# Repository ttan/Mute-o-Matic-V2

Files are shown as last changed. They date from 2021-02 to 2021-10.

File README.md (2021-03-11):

# Mute-o-Matic V2

Hardware mute button and end call for MS Teams, with led indicator. Since I'm using both macOs and Windows, it has a nice and comfortable slide SPST switch on the side to select OS.

This was my test project for the new Raspberry Pi Pico; with ~4€ you get a crazy good microprocessor and implementing HID functionality is extremelty trivial.

The project is written in CircuitPython, using the [Adafruit HID Library](https://circuitpython.readthedocs.io/projects/hid/en/latest/index.html). Remember to copy the library file on the Pico together with the code.py file. ~~I used a transparent plastic container because... well, that's the only thing I had in the house and there's lockdown due to COVID-19. Feel free to buy me a 3D Printer ❤️~~ I actually ended up buying a 3D printer so here you are the Mute-o-Matic v2 in its fancy plastic box!

You can find the design of the case in the *case* folder. It's my first design, so expect some filing here and there, it needs some millimetric adjustments.

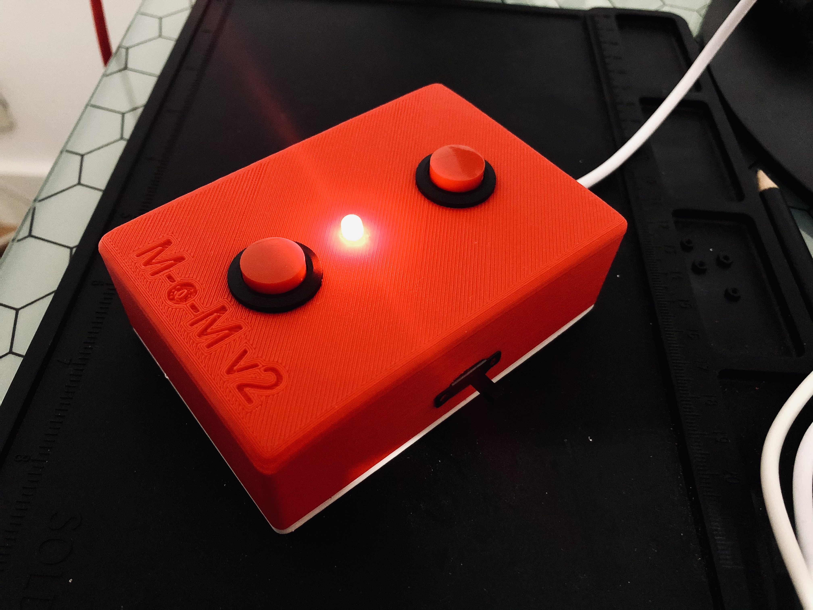
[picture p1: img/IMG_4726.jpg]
Mute-o-matic from the top


## A random Fritzing here

This is just to give you a idea of what's doing what.

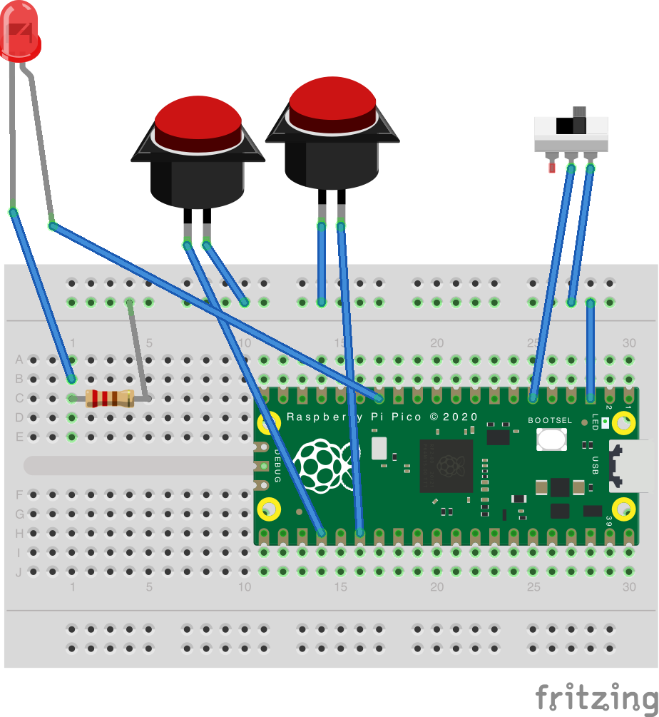
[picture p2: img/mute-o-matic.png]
Fritzing


## How it works
🚀 Rocket science! Jokes aside, it's just a HID which sends shortcuts defined in MS Teams, according to the OS selected with the side switch.
For Windows:
- *CTRL + Shift + M* to toggle the mute (and the led)
- *CTRL + Shift + B* to close the call (for strange reasons, this is not a documented shortcut on Teams official page)

For macOs (For macOs, cmd is mapped to GUI. I guess in Windows this would be the Windows logo):
- *CMD + Shift + M* to toggle the mute (and the led)
- *CMD + Shift + B* to close the call (guess what, this is also not a documented shortcut on Teams official page)

Easy. I just needed something to quickly mute/unmute the calls because I tend to get distracted and racing to find the proper button with the mouse is too hard.

## Parts used
- [Raspberry Pi Pico](https://www.raspberrypi.org/documentation/pico/getting-started/)
- 2 x Panel mount push button (Normally open)
- 1 x Red Led
- 1 x SPST slide switch
- 1 X 220 ohm resistance

## Windows only improvement
On my personal version of the Mute-o-Matic V2, I included another command which brings Teams on focus before toggling mute. This can be done with an idiot trick: pin Teams' icon in the bar (how is it called? the one below) and count what number is it starting from the left. You can switch to that with the shortcut: 
```
Alt + [Number]
```
You will need to do this twice because Teams will have two windows, the first one with the chat and all the other stuff and the second one with your active call. So, let's say I've put the icon as third in my Windows bar, the correct sequence will be:
```
Alt + 3
Alt + 3
CONTROL + Shift + M
```

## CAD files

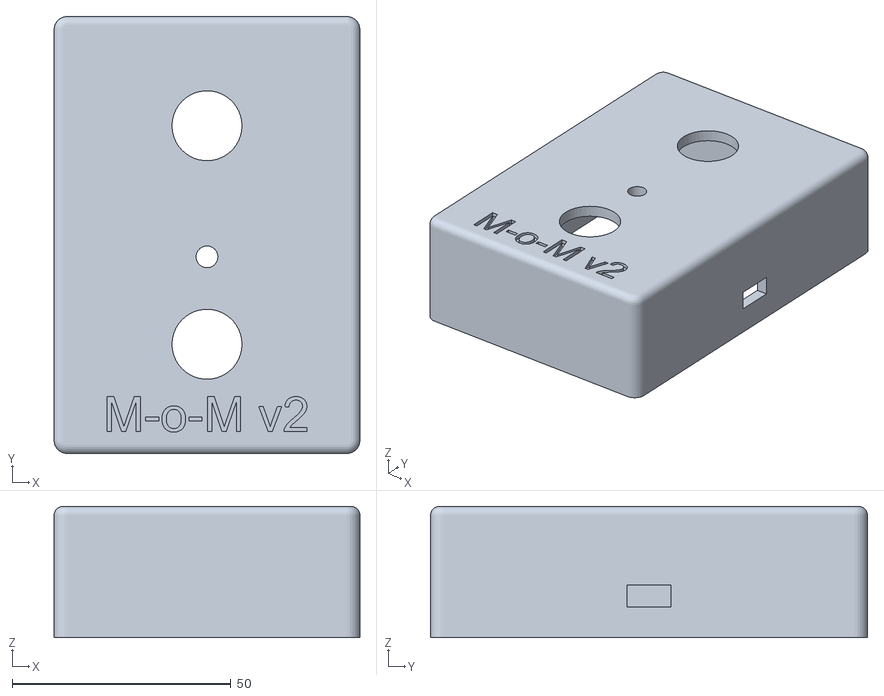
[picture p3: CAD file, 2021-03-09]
case/Lid_mute-o-matic v24_Body1_Lid.stl
70.0 x 100.0 x 30.0

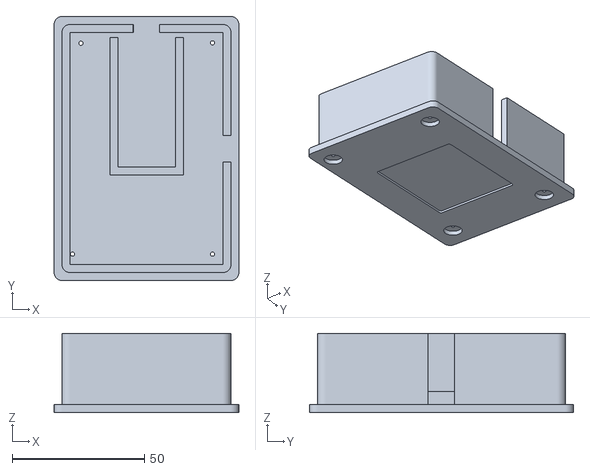
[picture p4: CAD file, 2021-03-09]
case/Bottom.stl
70.0 x 100.0 x 30.0

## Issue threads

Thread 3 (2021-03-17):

Basic Question

abbadabbatech, 2021-03-17:
Do you have a pic of inside your case?  Did you use a 1/4 breadboard or did you solder directly to the pico?

ttan, 2021-03-18:
Hi soldered everything directly to the pico,  everything on the top face so that it could easily fit into the case (if you check the 3D design of the bottom part of the case  you’ll get it immediately)

Closed 2021-03-18.

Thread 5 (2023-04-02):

Help with the windows optimization to bring up teams

FAROKHDUBASH, 2023-04-02:
Hi, Thanks for your wonderful tutorial on this project, I was able to build one & it works great.
I do not have much coding experience, however I did try to insert some lines of code before the mute function to bring up teams in the foreground like you had mentioned by Windows + Numeric position key, however it doesn't seem to work, like I have attached in the screenshot it just pulls up a blank window tab but does not switch to teams UI. Could you please help me out with the same?

Below is the snippet of the code.
if switch.value:
            # MacOs
            print("Button 1, Switch position 1")
            led.value = not led.value
            keyboard.send(Keycode.GUI, Keycode.THREE, Keycode.THREE)
            keyboard.send(Keycode.CONTROL, Keycode.SHIFT, Keycode.M)

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

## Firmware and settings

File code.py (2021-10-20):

import board
import time
import usb_hid

from digitalio import DigitalInOut, Direction, Pull
from adafruit_hid.keyboard import Keyboard
from adafruit_hid.keycode import Keycode

switch = DigitalInOut(board.GP4)
switch.direction = Direction.INPUT
switch.pull = Pull.UP

bt1 = DigitalInOut(board.GP18)
bt1.direction = Direction.INPUT
bt1.pull = Pull.UP

bt2 = DigitalInOut(board.GP20)
bt2.direction = Direction.INPUT
bt2.pull = Pull.UP

led = DigitalInOut(board.GP10)
led.direction = Direction.OUTPUT

keyboard=Keyboard(usb_hid.devices)

bt1Released = True
bt2Released = True

while True:
    if not bt1.value and bt1Released:
        bt1Released = False
        if switch.value:
            #MacOs
            print("Button 1, Switch position 1")
            led.value = not led.value
            keyboard.send(Keycode.GUI, Keycode.SHIFT, Keycode.M)
        else:
            #Windows
            print("Button 1, Switch position 2")
            led.value = not led.value
            keyboard.send(Keycode.CONTROL, Keycode.SHIFT, Keycode.M)
    if not bt2.value and bt2Released:
        bt2Released = False
        if switch.value:
            #MacOs
            print("Button 2, Switch position 1")
            keyboard.send(Keycode.GUI, Keycode.SHIFT, Keycode.B)
        else:
            #Windows
            print("Button 2, Switch position 2")
            keyboard.send(Keycode.CONTROL, Keycode.SHIFT, Keycode.B)
    if bt1.value and not bt1Released:
        bt1Released = true
    if bt2.value and not bt2Released:
        bt2Released = true

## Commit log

2021-03-01 Changed case!
2021-03-09 Uploaded 3D design of case
    STL files in case directory
    [Bottom.stl, Lid_mute-o-matic v24_Body1_Lid.stl]
2021-10-19 Added a button release flag - better state control
